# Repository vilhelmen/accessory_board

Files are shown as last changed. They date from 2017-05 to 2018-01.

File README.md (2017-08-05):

# RPi3 Accessory Board

A basic interface device designed for the Raspberry Pi 3, built for students learning realtime development.

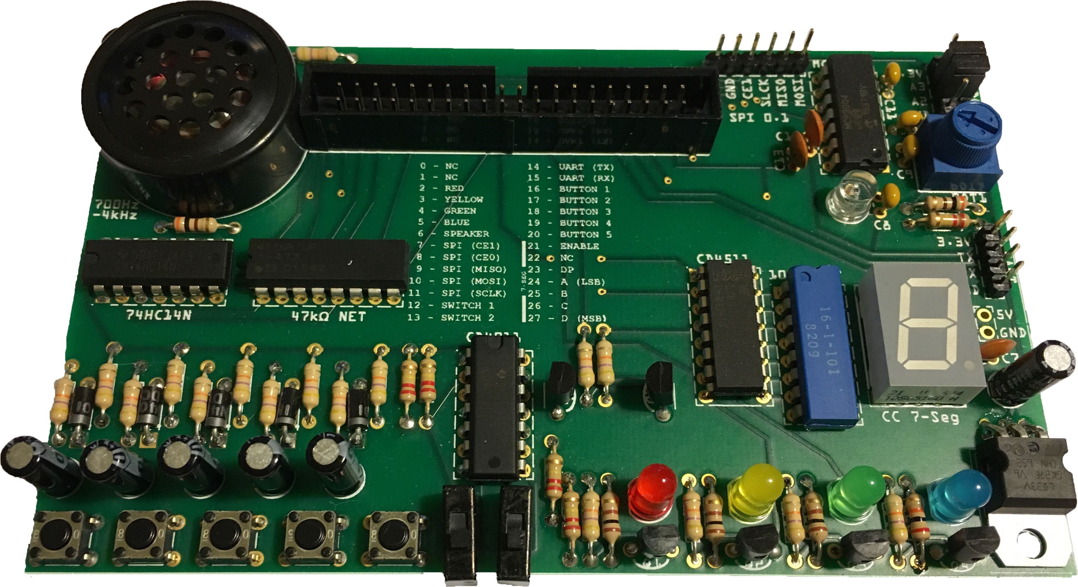
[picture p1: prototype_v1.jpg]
V1 device Version 1


# Features
* Five pushbuttons and two switches, with hardware debounce
* Four LEDs
* Speaker
* BCD 7-Segment display
* 10-Bit 4-channel SPI ADC
  * Potentiometer and phototransistor attached
* Headers:
  * Power (both 3.3V and 5V)
  * SPI bus with one available chip-select line
  * UART
* Labels:
  * Physical pin numbering
  * RPi3 pin numbering (BCM)
  * Speaker frequency range
  * ADC clock rate range

Designed with Fritzing, manufactured by Aisler ([board ordering available here](http://go.aisler.net/p/HHGNQZQE)), and all parts sourced from DigiKey ([cart export here](digikey_parts_export.csv))*.

Price is roughly $48 each, $62 per three boards, $28 per board for parts.

*Prototype LEDs sourced from Jameco, DigiKey LED quality has not been verified.

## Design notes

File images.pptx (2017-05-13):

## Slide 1

0 - NC
1 - NC
2 - RED
3 - YELLOW
4 - GREEN
5 - BLUE
6 - SPEAKER
7 - SPI (CE1)
8 - SPI (CE0)
9 - SPI (MISO)
10 - SPI (MOSI)
11 - SPI (SCLK)
12 - SWITCH 1
13 - SWITCH 2

14 - UART (TX)
15 - UART (RX)
16 - BUTTON 1
17 - BUTTON 2
18 - BUTTON 3
19 - BUTTON 4
20 - BUTTON 5
21 - ENABLE
22 - NC
23 - DP
24 – A (LSB)
25 - B
26 - C
27 – D (MSB)

7-SEG

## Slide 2

1
▲
▼
0

PIN BCM
27 0 - NC
28 1 - NC
3 2 - RED
5 3 - YELLOW
7 4 - GREEN
29 5 - BLUE
31 6 - SPKR
26 7 - CE1
24 8 - CE0
21 9 - MISO
19 10 - MOSI
23 11 - SCLK
32 12 - SW 1
33 13 - SW 2

PIN BCM
8 14 - UART (TX)
10 15 - UART (RX)
36 16 - BTN 1
11 17 - BTN 2
12 18 - BTN 3
35 19 - BTN 4
38 20 - BTN 5
40 21 - ENABLE
15 22 - NC
16 23 - DP
18 24 - A (LSB)
22 25 - B
37 26 - C
13 27 - D (MSB)

PIN
2 - +5V
4 - +5V (SPKR)
6 – GND
* - 3.3V Logic
BCM - RPi 3

SPI

7-SEG

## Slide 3

C1-5: 1µF
C6: 10µF
C7-17: 0.1µF
Q1-7: NPN
Q8: Phototrans. R27 Adj.
POT1: 10kΩ
R1-10, 15-19: 47kΩ
R11-14: 220kΩ
R20-22: 100Ω
R23: 22kΩ
R24: 200Ω
R25, 26: 47kΩ
R27: 100kΩ
R28: 300Ω
S1-5: Mom. NO
S6,7: SPDT BBM
SP1: 8Ω, > 0.15W

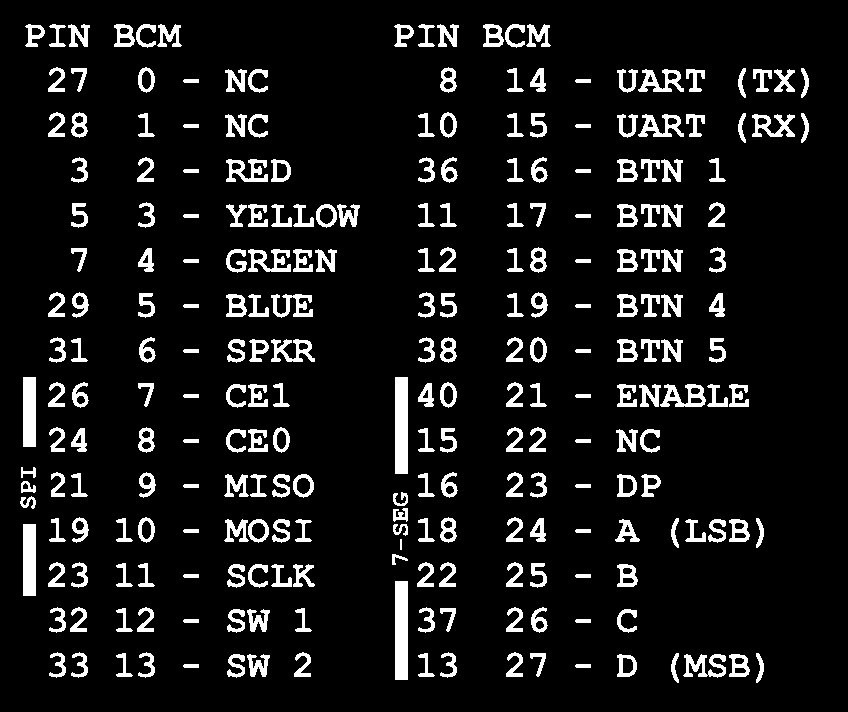
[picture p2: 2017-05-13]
pin_listing.png

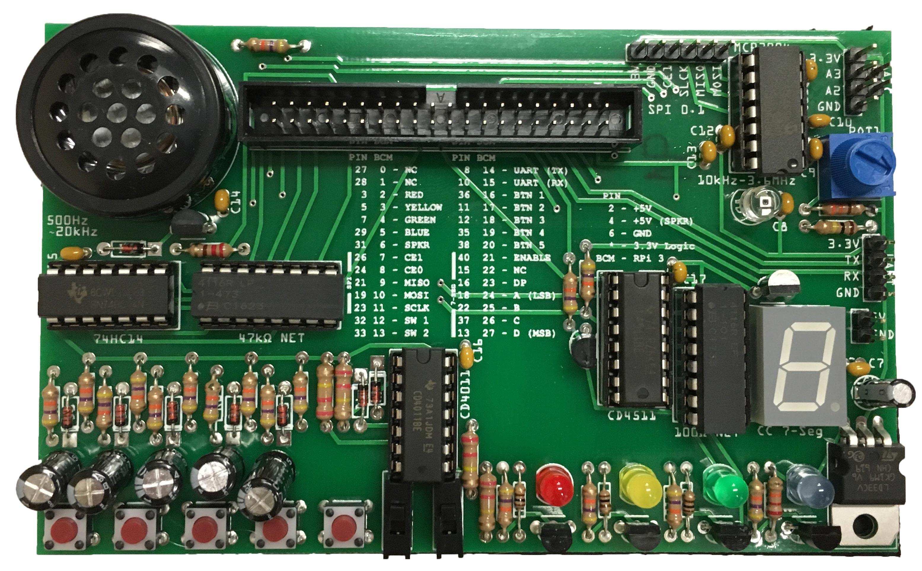
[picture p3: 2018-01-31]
rev_h.jpg

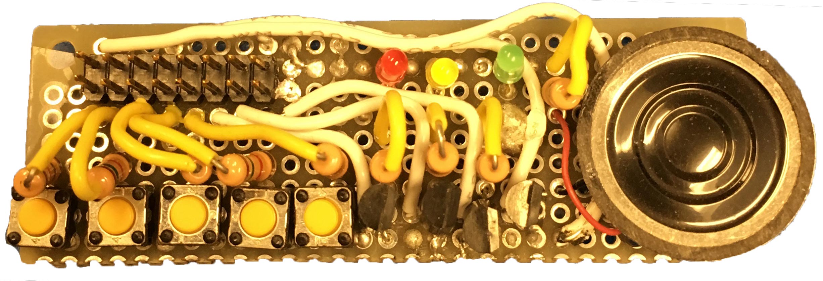
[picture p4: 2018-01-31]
original.jpg

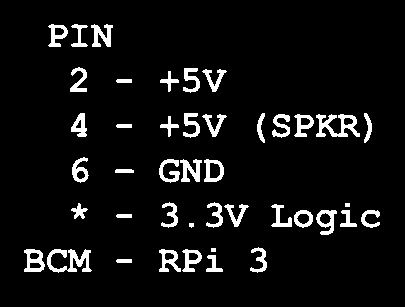
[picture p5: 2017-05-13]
aux_pin_data.png

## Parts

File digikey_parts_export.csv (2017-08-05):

Index | Quantity | Part Number | Description | Customer Reference | Available Quantity | Backorder Quantity | Unit Price USD | Extended Price USD
1 | 1 | MCP3004-I/P-ND | IC ADC 10BIT 2.7V 4CH SPI 14DIP |  | 1 | 0 | 2.14000 | 2.14
2 | 10 | BC3324-ND | CAP CER 0.1UF 50V X7R RADIAL |  | 10 | 0 | 0.13400 | 1.34
3 | 1 | TDSO5160-ND | DISPLAY 7-SEG. 13MM ORANGERED C. | 7-seg color option | 1 | 0 | 1.78000 | 1.78
4 | 1 | 751-1059-ND | AMBIENT LIGHT SENSOR 5MM 570NM |  | 1 | 0 | 0.74000 | 0.74
5 | 2 | S9000-ND | CONN JUMPER SHORTING TIN |  | 2 | 0 | 0.13000 | 0.26
6 | 1 | 4116R-1-101LF-ND | RES ARRAY 8 RES 100 OHM 16DIP |  | 0 | 1 | 0.84000 | 0.84
7 | 1 | 4116R-1-473LF-ND | RES ARRAY 8 RES 47K OHM 16DIP |  | 1 | 0 | 0.84000 | 0.84
8 | 1 | SN74HC14N | IC HEX SCHMITT-TRIG INV 14-DIP |  | 1 | 0 | 0.54000 | 0.54
9 | 1 | S1011EC-40-ND | CONN HEADER .100" SNGL STR 40POS |  | 1 | 0 | 0.74000 | 0.74
10 | 1 | S1111EC-40-ND | CONN HEADER .100" SNGL R/A 40POS | Optional | 1 | 0 | 0.92000 | 0.92
11 | 5 | 493-1157-ND | CAP ALUM 1UF 20% 160V RADIAL |  | 5 | 0 | 0.24000 | 1.20
12 | 1 | 296-2031-5-ND | IC GATE NAND 4CH 2-INP 14-DIP |  | 1 | 0 | 0.48000 | 0.48
13 | 1 | S9175-ND | CONN HEADER 2.54MM 40POS GOLD |  | 1 | 0 | 0.91000 | 0.91
14 | 1 | 497-1492-5-ND | IC REG LDO 3.3V 0.8A TO220AB |  | 1 | 0 | 0.59000 | 0.59
15 | 1 | 160-1127-ND | LED RED DIFF 5MM ROUND T/H |  | 1 | 0 | 0.36000 | 0.36
16 | 1 | 160-1852-ND | LED GRN DIFF 5MM ROUND T/H |  | 1 | 0 | 0.33000 | 0.33
17 | 1 | 67-1751-ND | LED BLUE DIFF 5MM ROUND T/H |  | 1 | 0 | 1.86000 | 1.86
18 | 1 | 3386F-103TLF-ND | TRIMMER 10K OHM 0.5W PC PIN | Multiple pin layouts supported | 1 | 0 | 2.48000 | 2.48
19 | 7 | 2N4401-APCT-ND | TRANS NPN 40V TO92 |  | 7 | 0 | 0.19000 | 1.33
20 | 5 | CF12JT220KCT-ND | RES 220K OHM 1/2W 5% AXIAL |  | 5 | 0 | 0.10000 | 0.50
21 | 3 | CF18JT100RCT-ND | RES 100 OHM 1/8W 5% CF AXIAL |  | 3 | 0 | 0.10000 | 0.30
22 | 1 | CF14JT22K0CT-ND | RES 22K OHM 1/4W 5% AXIAL |  | 1 | 0 | 0.10000 | 0.10
23 | 2 | CF14JT330RCT-ND | RES 330 OHM 1/4W 5% AXIAL |  | 2 | 0 | 0.10000 | 0.20
24 | 5 | 450-1650-ND | SWITCH TACTILE SPST-NO 0.05A 24V | Button style option | 5 | 0 | 0.10000 | 0.50
25 | 5 | 450-1804-ND | SWITCH TACTILE SPST-NO 0.05A 24V | Button style option | 0 | 5 | 0.10000 | 0.50
26 | 2 | 360-2131-ND | SWITCH SLIDE SPDT 3A 125V | Switch style option | 2 | 0 | 2.21000 | 4.42
27 | 2 | 360-2385-ND | SWITCH SLIDE SPDT 6A 125V | Switch style option | 2 | 0 | 3.41000 | 6.82
28 | 2 | 450-1598-ND | SWITCH SLIDE SPDT 250MA 125V | Switch style option | 2 | 0 | 0.93000 | 1.86
29 | 2 | 360-2383-ND | SWITCH SLIDE SPDT 0.4VA 28V | Switch style option | 2 | 0 | 3.98000 | 7.96
30 | 1 | 668-1136-ND | SPEAKER 8OHM 150MW TOP PORT 72DB | 17mm speaker also supported | 1 | 0 | 3.53000 | 3.53
31 | 2 | EG1903-ND | SWITCH SLIDE SPDT 200MA 30V | Switch style option | 2 | 0 | 0.58000 | 1.16
32 | 1 | TDSR1360-ND | DISPLAY 7-SEG. 13MM RED LC C.C.- | 7-seg color option | 1 | 0 | 1.78000 | 1.78
33 | 1 | TDSG5160-ND | DISPLAY 7-SEG. 13MM GREEN C.C. | 7-seg color option | 1 | 0 | 1.73000 | 1.73
34 | 1 | CF14JT100KCT-ND | RES 100K OHM 1/4W 5% AXIAL |  | 1 | 0 | 0.10000 | 0.10
35 | 3 | AE9989-ND | CONN IC DIP SOCKET 14POS TIN | Optional | 3 | 0 | 0.23000 | 0.69
36 | 3 | AE9992-ND | CONN IC DIP SOCKET 16POS TIN | Optional | 3 | 0 | 0.25000 | 0.75
37 | 1 | 493-12772-1-ND | CAP ALUM 10UF 20% 25V RADIAL |  | 1 | 0 | 0.28000 | 0.28
38 | 1 | 1125-1187-ND | LED YELLOW DIFF 5MM ROUND T/H |  | 1 | 0 | 0.35000 | 0.35
39 | 10 | 1N4148FS-ND | DIODE GEN PURP 100V 200MA DO35 |  | 10 | 0 | 0.05700 | 0.57
40 | 1 | 296-2072-5-ND | IC 7-SEG LED DECOD/DRVR 16-DIP |  | 1 | 0 | 0.56000 | 0.56
41 | 1 | 1N4001-TPMSCT-ND | DIODE GEN PURP 50V 1A DO41 |  | 1 | 0 | 0.11000 | 0.11
42 | 25 | CF14JT47K0CT-ND | RES 47K OHM 1/4W 5% AXIAL |  | 25 | 0 | 0.02880 | 0.72

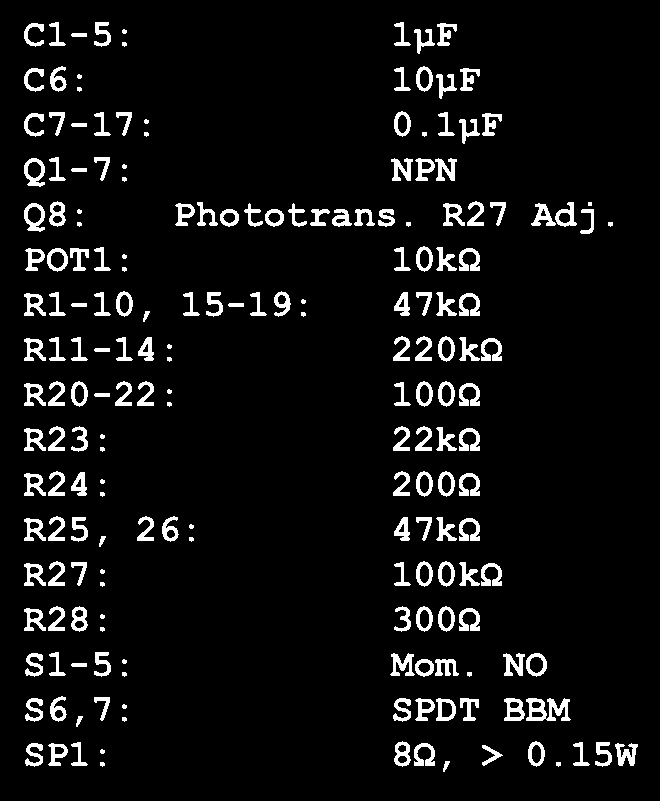
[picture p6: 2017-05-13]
parts_listing.png

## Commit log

2017-02-27 UGH WEB INTERFACE
    [New_board.fzz, New_board2.fzz]
2017-03-01 RC Debounce math
    [New_board2.fzz]
2017-03-02 Debounce circuits, LEDs hex inverter VCC resistor is ????? Board is getting large. Hmm. Debounce made it so much bigger. May need to toss.
    [New_board3.fzz]
2017-03-02 Wrong file
    [New_board3.fzz]
2017-03-04 CHAOS REIGNS
    [New_board3.fzz, New_board4.fzz]
2017-03-06 Rework pins to avoid GPIO0-4
    [New_board4.fzz]
2017-03-08 UART out. Need to figure out LEDs, and remove voltage divider
    [New_board4.fzz]
2017-03-08 MORE STUFF AHH
    [New_board4.fzz]
2017-03-09 A lot more done
    [New_board4.fzz]
2017-03-09 holy shit it routes
    [New_board4.fzz]
2017-03-09 Probably more accurate # of resistors
    [New_board4.fzz]
2017-03-10 First revision: Blue LED is SUPER GODDAMN BRIGHT
    [New_board4.fzz]
2017-03-11 Checked nand debounce and schmitt trigger
    [New_board4.fzz]
2017-03-11 one more note
    [New_board4.fzz]
2017-03-17 I think I've forgotten what I'm doing
    [Board_rev_A.fzz, Board_rev_B.fzz, Board_rev_C.fzz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]
2017-03-18 FUCK I FORGOT THE BCD RESISTORS
    [Auto_Networked.fzz, Board_rev_B.fzz, Board_rev_C.fzz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]
2017-03-19 Transistors! Also the blue LED. Also the BCD chip
    [Auto_Networked.fzz]
2017-03-19 Updated board
    [Auto_Networked.fzz]
2017-03-19 Retune speaker a bit
    [Auto_Networked.fzz]
2017-03-20 Fix switch inversion
    [Auto_Networked.fzz]
2017-03-20 Remove manual board, it's out of date now
    [Manual_Networked.fzz]
2017-03-20 Add 5V header, adjust text labels
    [Auto_Networked.fzz]
2017-03-22 Rev a - nice, Rev b - shitty
    [Board_rev_A.fzz, Rev_A.fzz, Rev_B.fzz]
2017-03-23 Revisions to ADC region. Add a trim pot? Mic?
    [Rev_A.fzz]
2017-03-23 REV_C - MCP3002 SPI ADC
    [Rev_A.fzz, Rev_C.fzz]
2017-03-24 ADC options. Rev A needs the ADC rewired maybe.
    [Rev_A.fzz, Rev_C.fzz, Rev_D.fzz]
2017-03-26 TMP out POT in, rework SPI header and regulator cap positions
    [Rev_E.fzz]
2017-03-27 Wire wiggling
    [Rev_E.fzz]
2017-03-28 Progress in fixing I2C in issue
    [Rev_F.fzz]
2017-03-28 Finish I2C I/O workaround
    [Rev_F.fzz]
2017-03-28 Rework traces, add alt pot layout
    Need to test new layout, photo resistor, and pot
    [Rev_F.fzz]
2017-03-29 Rework traces, another pot pin layout
    [Rev_F.fzz]
2017-03-30 Resistor changes/additions after testing
    [Rev_F.fzz]
2017-03-30 Speaker 5V, fix weird bad traces
    [Rev_F.fzz]
2017-03-30 Wriggle SPI header down one
    [Rev_F.fzz]
2017-03-30 Wriggle some labels
    [Rev_F.fzz]
2017-03-30 Rework analog caps, add caps for A2/3
    [Rev_F.fzz]
2017-03-31 Silkscreen stuff, final part wriggling
    [Rev_F.fzz]
2017-04-17 Post-production revision: spkr needs polarity sign
    [Rev_F.fzz]
2017-04-18 Update parts list, add cap to schematic
    [Rev_F.fzz]
2017-04-18 Revert because broken?
    [Rev_F.fzz]
2017-04-19 I blame aisler, idk what's wrong on my end
    [Rev_F.fzz]
2017-04-19 V1.1
    Add speaker cap (seems fine on prototype)
    Add speaker polarity sign
    Redo parts text
    Add version #
    (invert LED/transistor layout would be nice but seems complex)
    [Rev_F.fzz]
2017-04-20 Second speaker footprint
    Back and front text reworked/spaced
    Debounce parts wriggled down to make room
    J1 moved to the right
    SHIT THE SPI HEADER IS COVERED NOW FUCK
    [Rev_F.fzz]
2017-04-20 Rollback speaker, keep rest, adjust switches
    [Rev_F.fzz]
2017-04-20 Wriggle C8 power line
    [Rev_F.fzz]
2017-04-20 Adj LED4 power line
    [Rev_F.fzz]
2017-04-20 Add another pot pin layout
    [Rev_F.fzz]
2017-04-28 Tweaks V1.5 Adjust all text labels and make them better BCM/PHYS pin numbers Flip 47K net
    [Rev_A.fzz, Rev_B.fzz, Rev_C.fzz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]
2017-04-30 Add ADC frequency range
    [Rev_F.fzz]
2017-05-05 pot code update, working on board schematic
    [Rev_F.fzz]
2017-05-05 rework in progress
    [Rev_F.fzz]
2017-05-06 New speaker stuff, pin 1 label, updated text, caps everywhere
    [Rev_F.fzz]
2017-05-13 New enable circuitry and labels
    [Rev_H.fzz]
2017-05-30 Version bump, toss old file
    [Rev_G.fzz, Rev_H.fzz]
2017-08-05 Readme, parts list, links, etc
    [digikey_parts_export.csv]
